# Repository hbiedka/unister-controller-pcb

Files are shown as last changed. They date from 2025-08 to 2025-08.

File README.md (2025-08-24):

## Dude, I need professional-looking PCB with <n> dry-contact relays, <m> 230V on/off relays, <x> inputs and <y> opto-isolated inputs

After ~10 similar projects I used to make using perfboards and PCBs etched at home I have created this PCB project to utillize it in as many automation projects as possible.

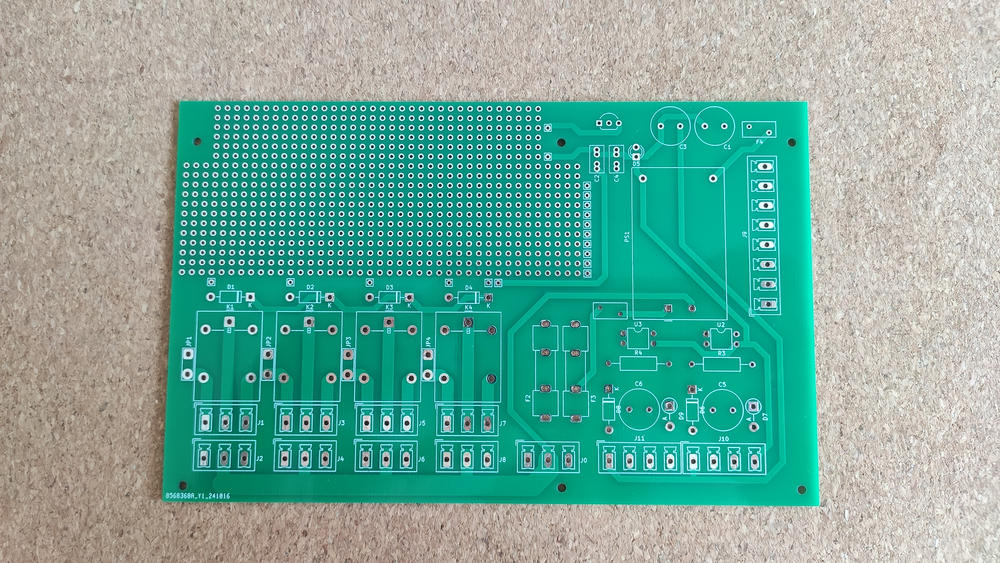
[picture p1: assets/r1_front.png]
PCB front
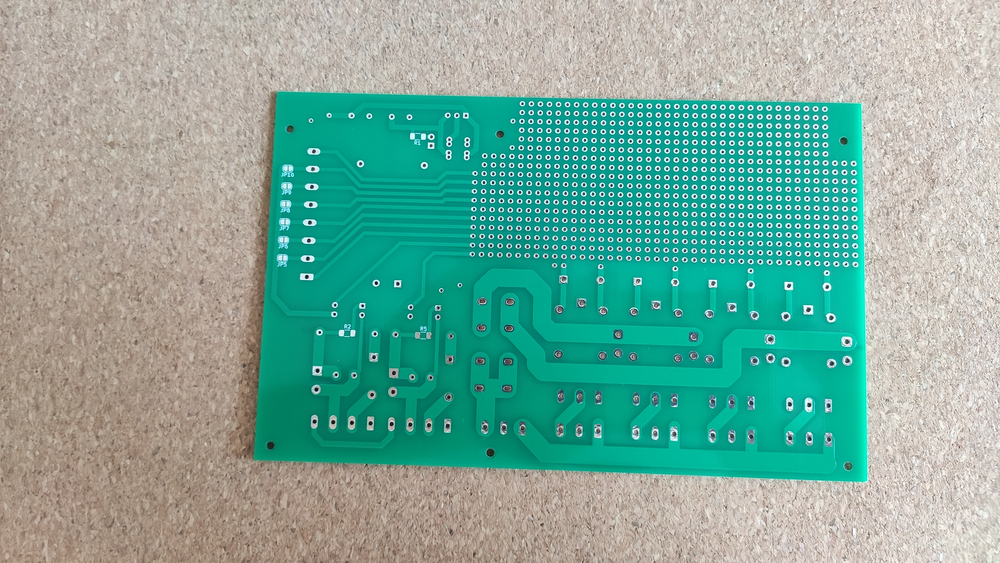
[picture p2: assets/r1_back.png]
PCB back
|  |  |
|---|---|
| Front | Back |

# What does it have

* 2.54 mm perfboard-like field for whatever you want
* 4 relays
  * NO/NC dry contact
  * fused AC output with N and PE split into 2 circuits protected by separated fuses 
* 8x terminal outputs for general purpose (6 of them can be easily connected to GND
* 2x optoinolated input
  * dry contact
  * low-voltage wet contact
  * AC wet contact
* AC to low voltage converted (12V, 5V or similar) using HiLink HLK series
* optional LDO or DC/DC converter (the net is called 5V but it can be any voltage by using proper LDO or converter)
* power LED diode

# Some projects I have done based on this PCB

| | |
|---|---|
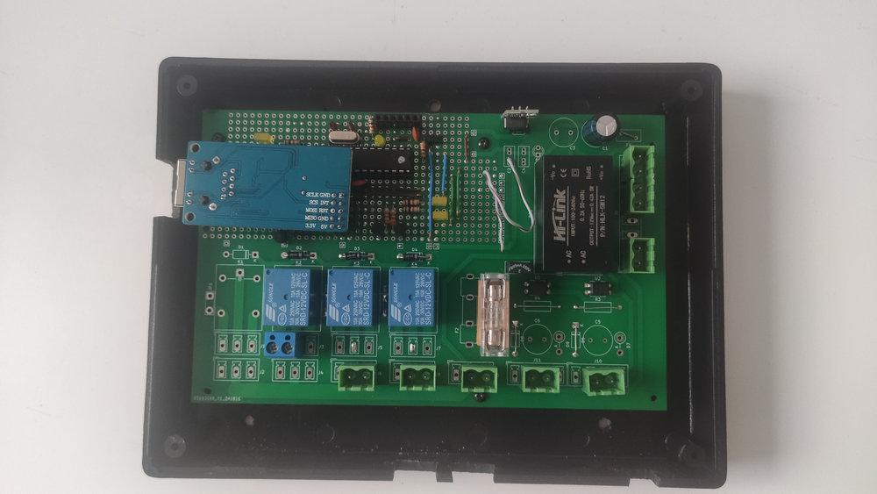
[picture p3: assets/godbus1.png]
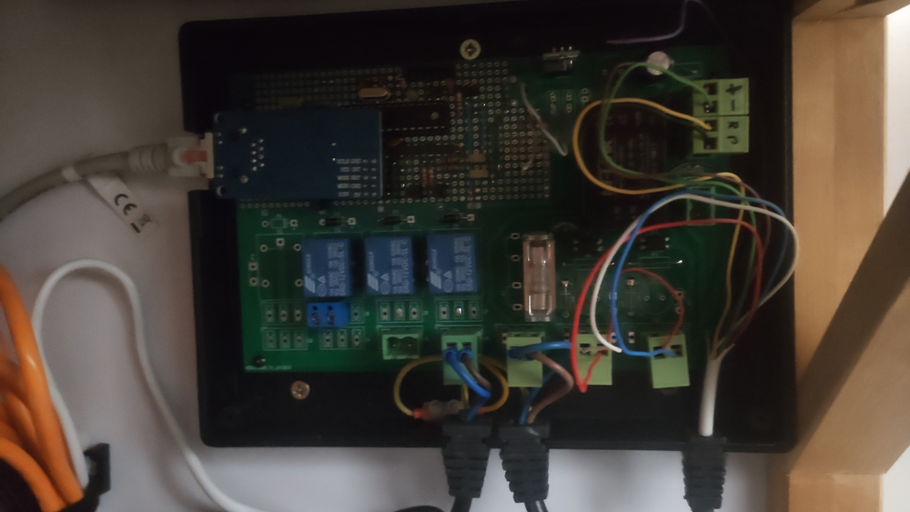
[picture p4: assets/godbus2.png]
|  |  |

# Configuration and customisation options

## Relays

| Footprint | Dry contact output | Wet contact output (AC voltage out) |
|---|---|---|
| Kn_DRY (closer to relay) | Populate | Do not populate |
| Kn_230VAC (closer to edge) | Do not populate | Populate |
| KN_WET jumper | Do not populate | Populate using ~1mm^2 wire |

If you are using wet contact output(s), remember to populate F2 or F3 by fuse holder and provide a proper fuse. **Remember to select proper amperage based on fuse rate and wiring**

### Negative voltage controlled coils with common VCC voltage (recommended)
If you would like to use eg. NPN or MOSFET-N transistor to drive relay coils and supply it from Hi-Link supply voltage output:
* Short COM_RELAY with VCC - the best way is to use solder nieghbor points near D4
* Solder suppression diodes according to PCB symbol (bar is cathode)

### Negative voltage controlled coils with common LDO/converter output voltage
Like above, but short COM_RELAY to 5V net

### Positive voltage controlled coils with common ground
If you would like to use PNP or MOSFET-P transistors to drive relay coils:
* Short COM_RELAY with GND
* Solder suppression diodes **opposite to PCB symbol** (bar is anode)

## Optoisolated inputs

| Footprint | Dry contact (positive) | Dry contact (negative) | Wet contact (low voltage) | Wet contact (AC voltage) |
|---|---|---|---|---|
| J10/J11 | Solder 2-pole terminal to pins 1-2 (left), short pins 3-4 | Solder 2-pole terminal to pins 3-4 (right), short pins 1-2 | Solder 2-pole terminal to pins 2-3 (middle) | Solder 2-pole terminal to pins 2-3 (middle) |
| D6/D8 | Short | Short | Short | Populate |
| R3/R4 | Short | Short | Short | Populate |
| C4/C6 | Do not populate | Do not populate | Do not populate | Populate |
| D7/D9 | Do not populate | Do not populate | Do not populate | Populate |

For all cases:
* Populate R2/R5 - use proper resistance to provide suitable diode current with nominal voltage
* Use PC817 or similar transoptor

## Single DC voltage (no DC/DC or LDO)

Short pins 1 and 3 of U1

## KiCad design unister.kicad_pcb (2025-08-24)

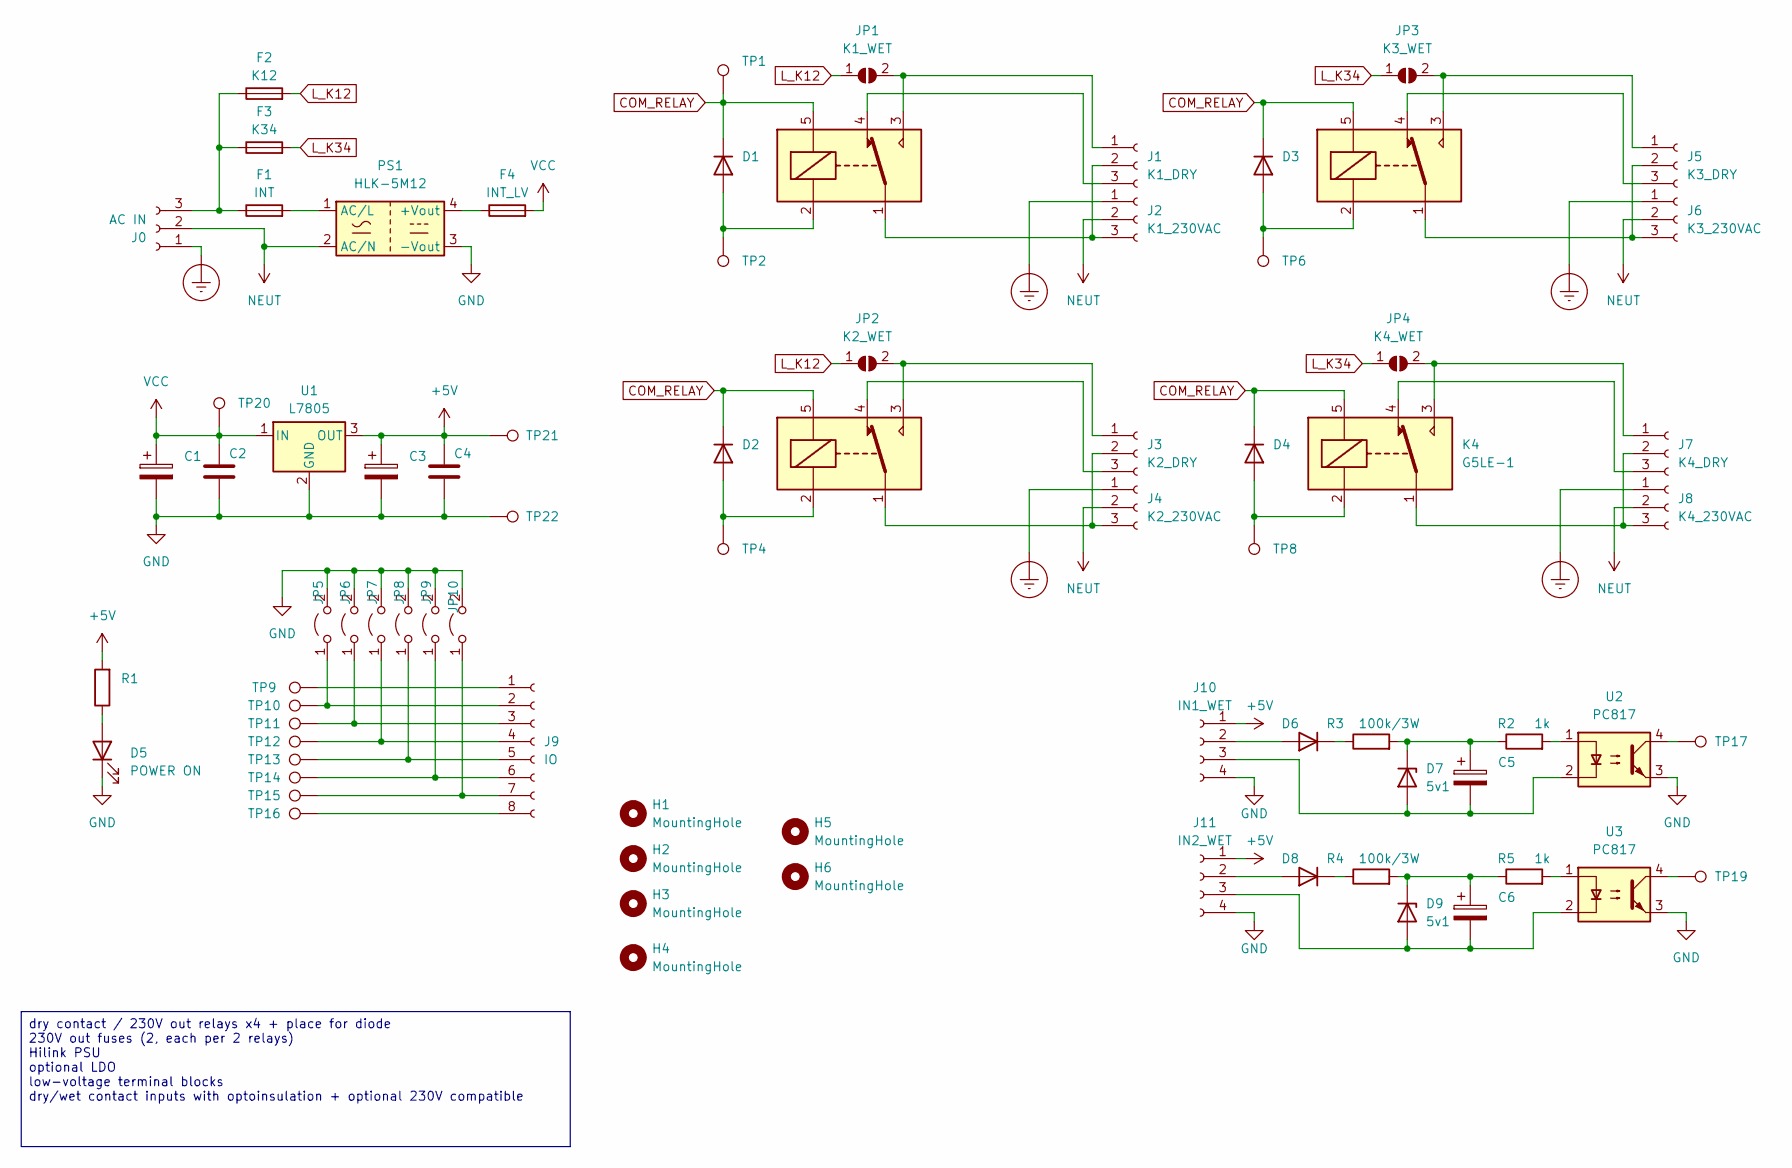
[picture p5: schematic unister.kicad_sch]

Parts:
C1, C3, C5, C6: C_Polarized; C_Radial_D10.0mm_H20.0mm_P5.00mm
C2, C4: C; C_Rect_L7.0mm_W3.5mm_P2.50mm_P5.00mm
D1, D2, D3, D4: 1N4007; D_DO-41_SOD81_P10.16mm_Horizontal
D5: POWER ON; LED_D3.0mm
D6, D8: D; D_DO-41_SOD81_P10.16mm_Horizontal
D7, D9: 5v1; D_DO-15_P5.08mm_Vertical_AnodeUp
F1: INT; Fuse_BelFuse_0ZRE0005FF_L8.3mm_W3.8mm
F2: K12; Fuseholder_Clip-5x20mm_Keystone_3512_Inline_P23.62x7.27mm_D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
F3: K34; Fuseholder_Clip-5x20mm_Keystone_3512_Inline_P23.62x7.27mm_D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
F4: INT_LV; Fuse_BelFuse_0ZRE0005FF_L8.3mm_W3.8mm
H1, H2, H3, H4, H5, H6: MountingHole; MountingHole_2.2mm_M2
J0: AC IN; PhoenixContact_MCV_1,5_3-G-5.08_1x03_P5.08mm_Vertical
J1: K1_DRY; PhoenixContact_MCV_1,5_3-G-5.08_1x03_P5.08mm_Vertical
J2: K1_230VAC; PhoenixContact_MCV_1,5_3-G-5.08_1x03_P5.08mm_Vertical
J3: K2_DRY; PhoenixContact_MCV_1,5_3-G-5.08_1x03_P5.08mm_Vertical
J4: K2_230VAC; PhoenixContact_MCV_1,5_3-G-5.08_1x03_P5.08mm_Vertical
J5: K3_DRY; PhoenixContact_MCV_1,5_3-G-5.08_1x03_P5.08mm_Vertical
J6: K3_230VAC; PhoenixContact_MCV_1,5_3-G-5.08_1x03_P5.08mm_Vertical
J7: K4_DRY; PhoenixContact_MCV_1,5_3-G-5.08_1x03_P5.08mm_Vertical
J8: K4_230VAC; PhoenixContact_MCV_1,5_3-G-5.08_1x03_P5.08mm_Vertical
J9: IO; PhoenixContact_MCV_1,5_8-G-5.08_1x08_P5.08mm_Vertical
J10: IN1_WET; PhoenixContact_MCV_1,5_4-G-5.08_1x04_P5.08mm_Vertical
J11: IN2_WET; PhoenixContact_MCV_1,5_4-G-5.08_1x04_P5.08mm_Vertical
JP1: K1_WET; TestPoint_2Pads_Pitch5.08mm_Drill1.3mm
JP2: K2_WET; TestPoint_2Pads_Pitch5.08mm_Drill1.3mm
JP3: K3_WET; TestPoint_2Pads_Pitch5.08mm_Drill1.3mm
JP4: K4_WET; TestPoint_2Pads_Pitch5.08mm_Drill1.3mm
JP5, JP6, JP7, JP8, JP9, JP10: SolderJumper-2_P1.3mm_Open_RoundedPad1.0x1.5mm
K1, K2, K3, K4: G5LE-1; Relay_SPDT_Omron-G5LE-1
PS1: HLK-5M12; Converter_ACDC_HiLink_HLK-5Mxx
R1: R; R_1206_3216Metric_Pad1.30x1.75mm_HandSolder
R2, R5: 1k; R_1206_3216Metric_Pad1.30x1.75mm_HandSolder
R3, R4: 100k/3W; R_Axial_DIN0309_L9.0mm_D3.2mm_P15.24mm_Horizontal
TP1, TP2, TP4, TP6, TP8, TP9, TP10, TP11, TP12, TP13, TP14, TP15, TP16, TP17, TP19, TP20, TP21, TP22: TestPoint; Pin_D0.7mm_L6.5mm_W1.8mm_FlatFork
U1: L7805; TO-92L_Inline_Wide
U2, U3: PC817; DIP-4_W7.62mm

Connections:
+5V: C3.1, C4.1, J10.1, J11.1, R1.2, TP21.1, U1.3 (OUT)
COM_RELAY: D1.1 (K), D2.1 (K), D3.1 (K), D4.1 (K), K1.5, K2.5, K3.5, K4.5, TP1.1
Earth_Protective: J0.1, J2.1, J4.1, J6.1, J8.1
GND: C1.2, C2.2, C3.2, C4.2, D5.1 (K), J10.4, J11.4, JP5.2 (B), JP6.2 (B), JP7.2 (B), JP8.2 (B), JP9.2 (B), JP10.2 (B), PS1.3 (-Vout), TP22.1, U1.2 (GND), U2.3, U3.3
L_K12: F2.2, JP1.1 (A), JP2.1 (A)
L_K34: F3.2, JP3.1 (A), JP4.1 (A)
NEUT: J0.2, J2.2, J4.2, J6.2, J8.2, PS1.2 (AC/N)
unnamed: D1.2 (A), K1.2, TP2.1
unnamed: D2.2 (A), K2.2, TP4.1
unnamed: D3.2 (A), K3.2, TP6.1
unnamed: D4.2 (A), K4.2, TP8.1
unnamed: D5.2 (A), R1.1
unnamed: D6.2 (A), J10.2
unnamed: D6.1 (K), R3.1
unnamed: C5.2, D7.2 (A), J10.3, U2.2
unnamed: C5.1, D7.1 (K), R2.1, R3.2
unnamed: D8.2 (A), J11.2
unnamed: D8.1 (K), R4.1
unnamed: C6.2, D9.2 (A), J11.3, U3.2
unnamed: C6.1, D9.1 (K), R4.2, R5.1
unnamed: F1.1, F2.1, F3.1, J0.3
unnamed: J1.1, JP1.2 (B), K1.3
unnamed: J1.2, J2.3, K1.1
unnamed: J1.3, K1.4
unnamed: J3.1, JP2.2 (B), K2.3
unnamed: J3.2, J4.3, K2.1
unnamed: J3.3, K2.4
unnamed: J5.1, JP3.2 (B), K3.3
unnamed: J5.2, J6.3, K3.1
unnamed: J5.3, K3.4
unnamed: J7.1, JP4.2 (B), K4.3
unnamed: J7.2, J8.3, K4.1
unnamed: J7.3, K4.4
unnamed: J9.1, TP9.1
unnamed: J9.2, JP5.1 (A), TP10.1
unnamed: J9.3, JP6.1 (A), TP11.1
unnamed: J9.4, JP7.1 (A), TP12.1
unnamed: J9.5, JP8.1 (A), TP13.1
unnamed: J9.6, JP9.1 (A), TP14.1
unnamed: J9.7, JP10.1 (A), TP15.1
unnamed: J9.8, TP16.1
unnamed: F4.1, PS1.4 (+Vout)
unnamed: F1.2, PS1.1 (AC/L)
unnamed: R2.2, U2.1
unnamed: R5.2, U3.1
unnamed: TP17.1, U2.4
unnamed: TP19.1, U3.4
VCC: C1.1, C2.1, F4.2, TP20.1, U1.1 (IN)

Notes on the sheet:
dry contact / 230V out relays x4 + place for diode 230V out fuses (2, each per 2 relays) Hilink PSU optional LDO low-voltage terminal blocks dry/wet contact inputs with optoinsulation + optional 230V compatible

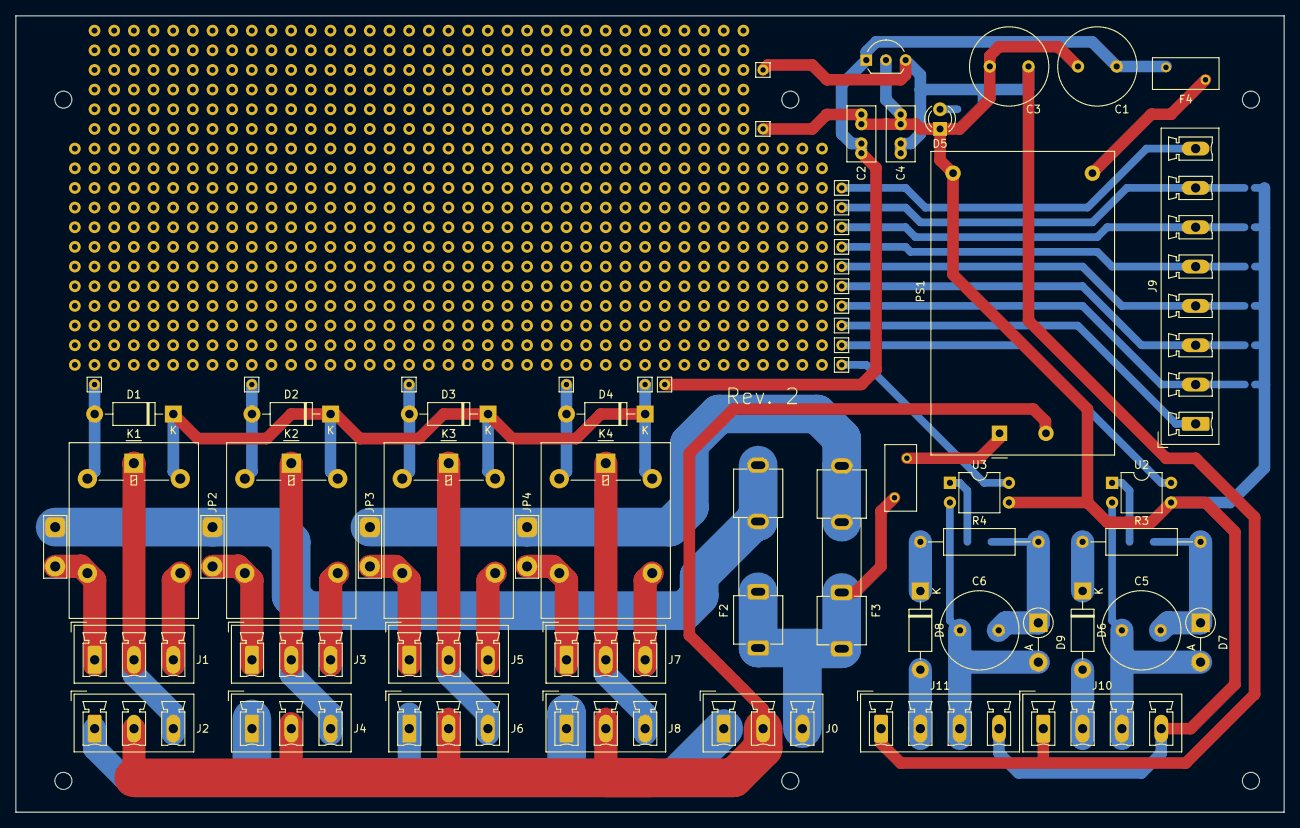
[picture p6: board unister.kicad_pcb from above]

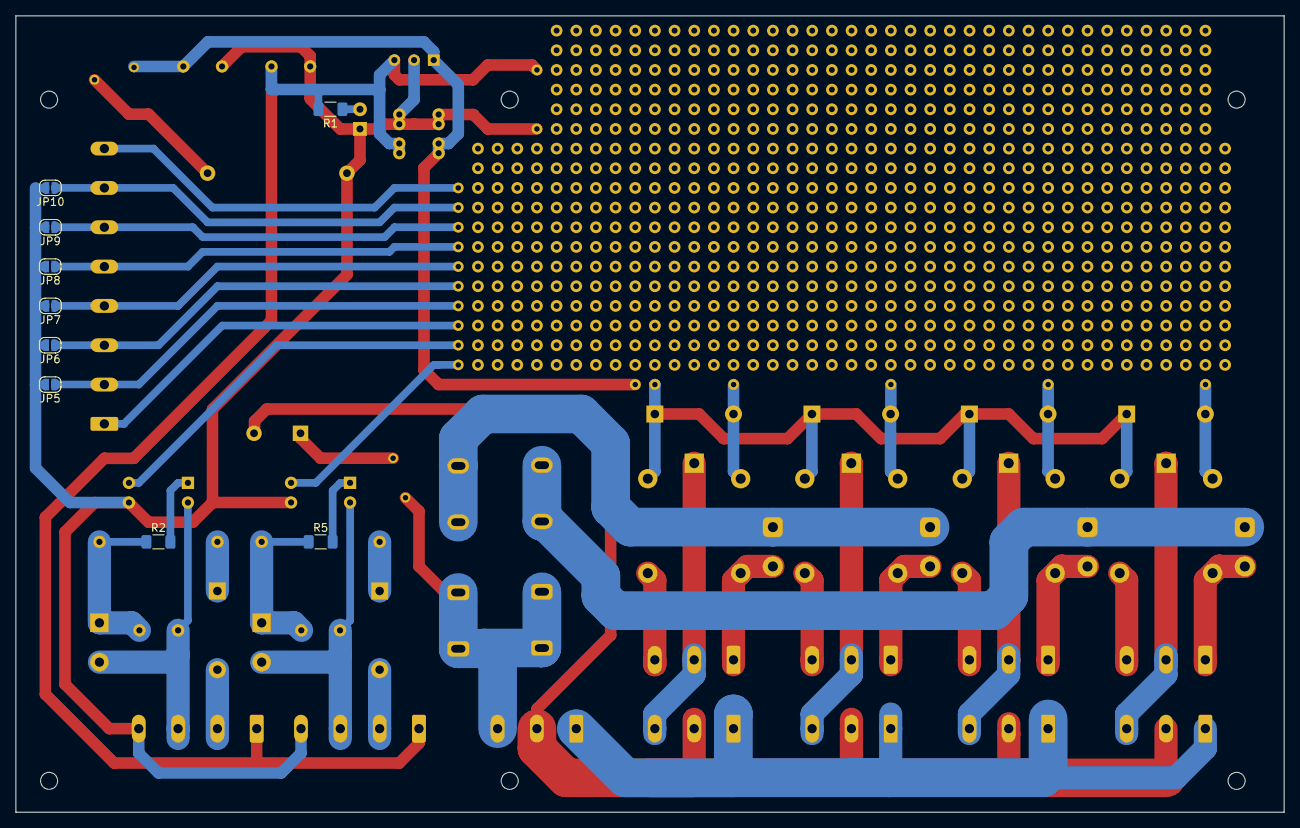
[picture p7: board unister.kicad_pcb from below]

Board: 2 copper layers, 163.8 x 102.9 mm, 78 parts (9 on the bottom side), 48 nets.

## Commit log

2025-07-27 Version 1: add production files
    [unister-B_Cu.gbl, unister-B_Mask.gbs, unister-B_Paste.gbp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]
2025-08-12 Revision 2: Grow fuses distance, move mounting holes
    [unister.kicad_pcb]
2025-08-24 Revision 2: Add print, export production files
    [unister-B_Cu.gbl, unister-B_Mask.gbs, unister-B_Paste.gbp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]
